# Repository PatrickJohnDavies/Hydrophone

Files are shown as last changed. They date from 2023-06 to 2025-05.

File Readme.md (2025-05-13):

# Intro
This project describes the construction of a stereo audio hydrophone system by building upon the hydrophone design from [Sound Sleuth](https://www.youtube.com/watch?v=KQ_KqJDaOM4). 
Major parts of the system are:
- Hydrophone with preampifier
- Amplifier and headphone driver
- Stand for underwater stereo sound seperation 

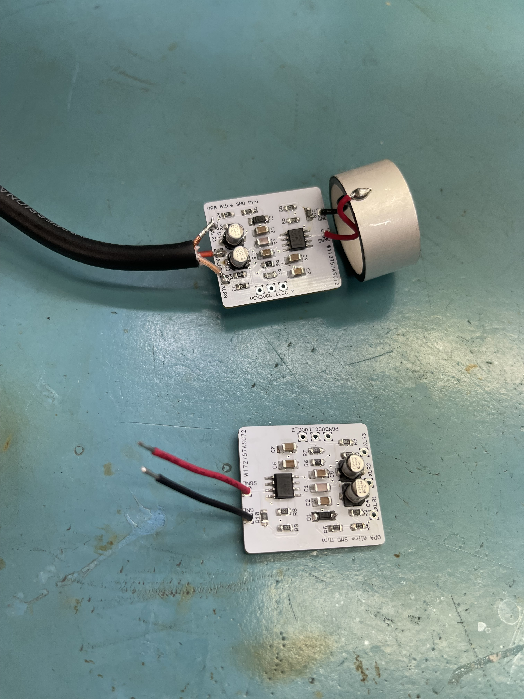
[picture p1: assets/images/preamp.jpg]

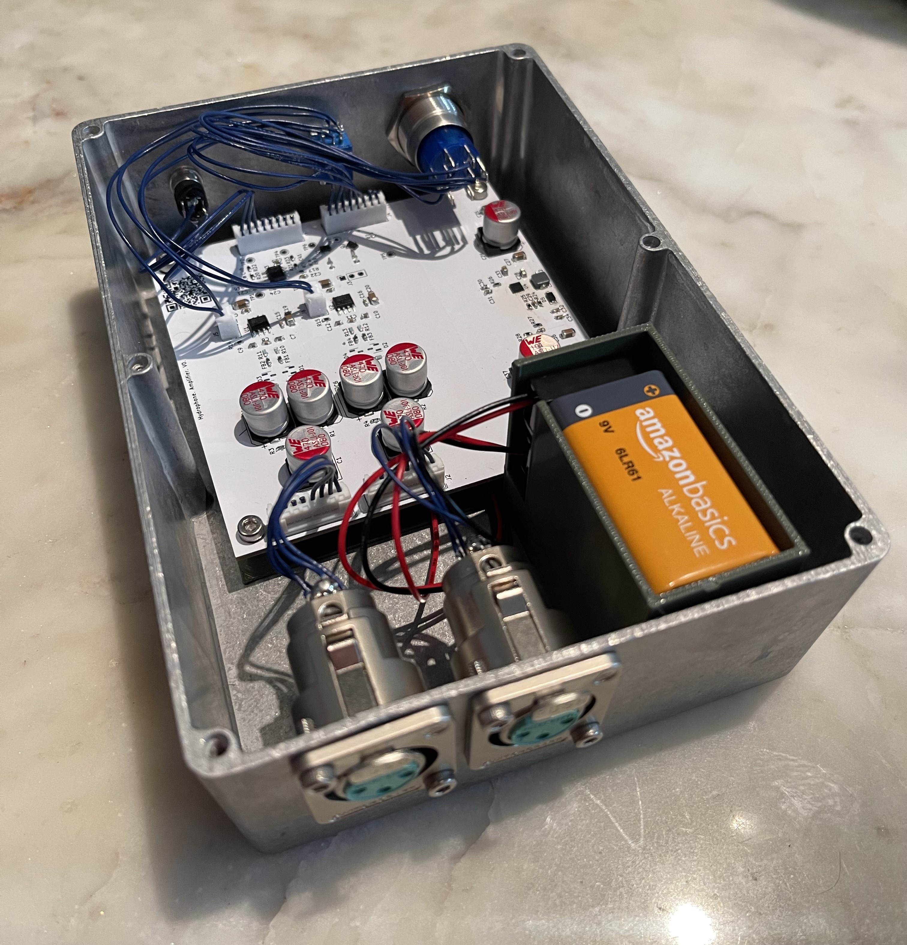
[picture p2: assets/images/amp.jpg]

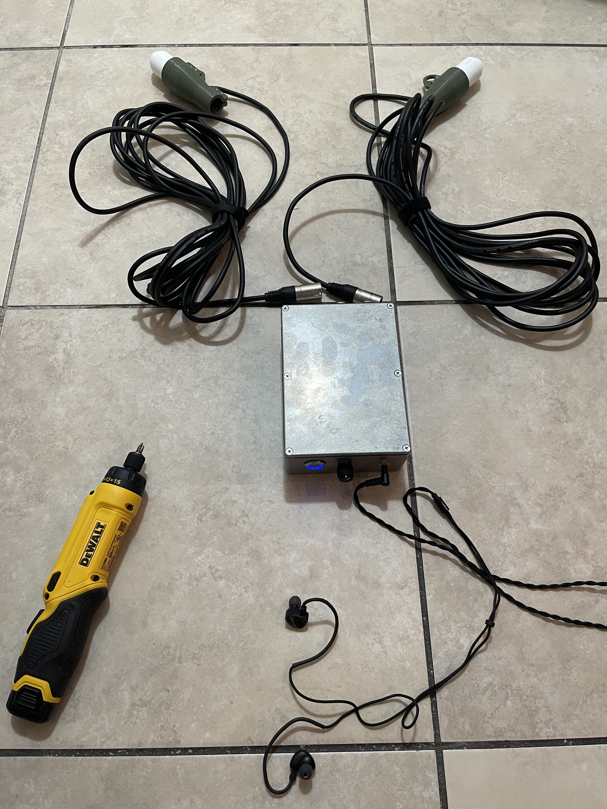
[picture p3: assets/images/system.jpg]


# Release Notes:
* V0
    * Bug. Instrumentation amplifier (U1, U2) footprint is incorrent. Therefore switched to AD620. Instrumentation amplifiers with this pinout seem have lower bandwidth.
    * Bug. Q2 has its drain and source reversed.

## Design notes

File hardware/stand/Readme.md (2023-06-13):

Human ear spacing: 0.175 m
Speed of sound in air: 331 m/s
Speed of sound in water: 1480 m/s
Hydrophone spacing in water: 0.175 m * 1480 m/s / 331 m/s = 0.782 m = 30.80 in

BOM:
- 4x https://www.homedepot.com/p/Charlotte-Pipe-1-2-in-PVC-Schedule-40-Socket-Cap-PVC021160600HD/203811669
- 4x https://www.homedepot.com/p/Charlotte-Pipe-1-2-in-PVC-Schedule-40-S-x-S-x-S-Tee-PVC024000600HD/203812195
- 2x https://www.homedepot.com/p/Charlotte-Pipe-1-2-in-x-10-ft-PVC-Schedule-40-Plain-End-DWV-Pipe-PVC-04005-0600/100348471
- 8x M3 Bolts

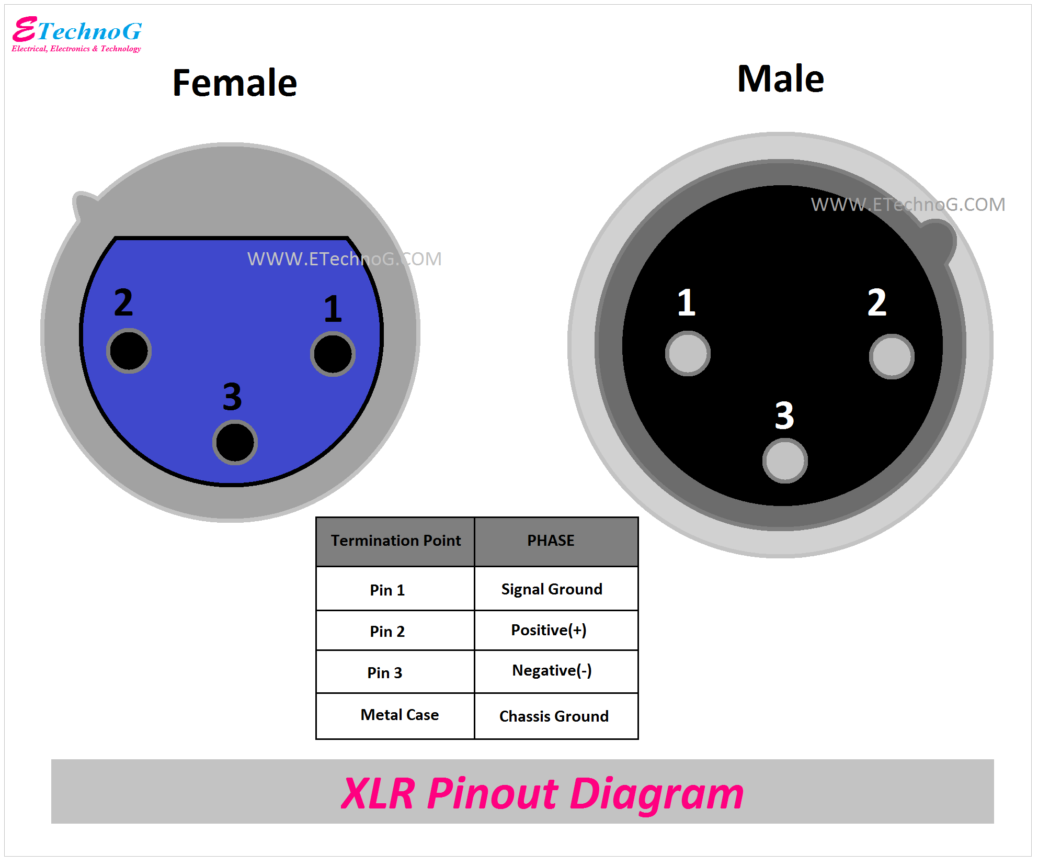
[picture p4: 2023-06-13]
hardware/pre amplifier/XLR Pinout Diagram.png

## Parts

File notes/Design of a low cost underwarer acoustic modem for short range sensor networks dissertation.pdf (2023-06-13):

UNIVERSITY OF CALIFORNIA, SAN DIEGO

Design of a Low-cost Underwater Acoustic Modem for Short-Range Sensor Networks

A thesis submitted in partial satisfaction of the requirements for the degree Doctor of Philosophy

in

Computer Science and Engineering

by

Bridget Benson

Committee in charge:

Professor Ryan Kastner, Chair Professor Rajesh Gupta
Professor John Hildebrand
Professor Tajana Rosing
Professor Curt Schurgers

2010

Copyright

Bridget Benson, 2010

All rights reserved.

The thesis of Bridget Benson is approved, and it is ac-

ceptable in quality and form for publication on microfilm

and electronically:

Chair

University of California, San Diego

2010

iii

DEDICATION

To everyone who told me not to give up.

iv

EPIGRAPH

Enjoy the Process

—Dr. Dan Clark

v

TABLE OF CONTENTS

Chapter 3 Comparison or RF, Optical and Acoustic Communication Un-

vi

vii

Chapter 8 System Tests | 111
8.1 Analog Testing | 111
8.2 Digital Testing | 114
8.2.1 | Hard Wired Tests | 114
8.2.2 | Bucket Tests | 118
8.3 Integrated Tests | 120
8.3.1 | Multipath Measurements | 120
8.3.2 | Tank Tests | 121
8.3.3 | Canyon View Pool Tests | 123
8.3.4 | Westlake Tests | 124
8.3.5 | Integrated System Test Summary | 128
8.4 Summary | 128
Chapter 9 Deployment Considerations | 130
9.1 Linear Programming Model | 130
9.2 Battery Considerations | 136
9.3 Housing Considerations | 137
9.4 Marine Life Considerations | 138
9.4.1 | Physical Effects | 138
9.4.2 | Acoustic Effects | 139
9.5 Summary | 140
Chapter 10 Future Improvements | 141
Appendix A Bill Of Materials | 143
Bibliography | 145

viii

LIST OF FIGURES

Figure 3.3: RF Wavelength vs. Frequency in Sea Water, Fresh Water, and

Figure 3.4: Air to Water Refraction Loss as a Function of Frequency . . . . 16

Figure 3.7: The Spectral Transmittance over the upper 10m of water for

Figure 3.8: Acoustic Absorption as a function of temperature, pressure, and

Figure 3.11: Source Level vs. Transmission Distance for a 40 kHz carrier an ambient noise of 50 dB re 1 uPa at various levels of SNR . . . . 28 Figure 3.12: Ray Trace for a 40kHz source with a 15 degree beam angle placed at 10 meters depth in a body of water 11 meters deep

Figure 5.1: (a) Raw PZT , (b) Prepotted Transducer , (c) and Potted Trans-

Figure 6.3: Class B Amplifier Input/Output Characteristic for one transistor 61 Figure 6.4: Class AB Amplifier Input/Output Characteristic for one tran-

Figure 6.5: Block diagram of a basic switching or PWM (Class-D) amplifier 63 Figure 6.6: Block diagram of the power amplifier design making use of a class AB and class D amplifier to achieve linearity and efficiency 63

ix

Figure 6.11: Maximum Power Transfer is acheived when ZS matches ZL . . 68
Figure 6.12: Electrical Equiavalent Circuit Model for a Transducer | 69
Figure 6.13: Measured and Simulated Current of the Transducer | 70
Figure 6.14: Measured and Simulated Impedance Magnitude of the Transducer 71 Figure 6.15: Measured and Simulated Impedance Phase of the Transducer . 72
Figure 6.16: Transducer Impedance Matching Circuit | 73
Figure 6.17: Impedance Matched Measured and Simulated Current of the
Transducer | 74
Figure 6.18: Impedance Matched Measured and Simulated Impedance Mag-
nitude of the Transducer | 75
Figure 6.19: Impedance Matched Measured and Simulated Impedance Phase
of the Transducer | 76
Figure 6.20: Estimated Power Coupled into the Transducer | 77
Figure 6.21: Receiver Block Diagram | 78
Figure 6.22: Overall Receiver Gain | 79

Figure 7.1: Block diagram of classic matched filter FSK demodulator . . . 82 Figure 7.2: Bit Error Rate of MFSK and MPSK for a given probability of
error | 83
Figure 7.3: Block diagram of a coherant PSK receiver | 84
Figure 7.4: Block Diagram of Complete Digital Receiver | 88
Figure 7.5: Block Diagram of FSK Modulator | 90
Figure 7.6: Block Diagram of Digital Down Converter | 91
Figure 7.7: Process of Symbol Synchronization | 92
Figure 7.8: Auto Correlation (blue) and Cross Correlation (black) of Orthogonal Gold (a), Walsh (b) and PN (c) Reference Codes . . . 95 Figure 7.9: MATLAB simulation of symbol synchronization for underwater
FSK | 97
Figure 7.10: Block Diagram of Symbol Synchronization for Underwater FSK 98 Figure 7.11: Hardware Units of Correlation Implementation for Underwater
FSK | 100
Figure 7.12: Control Structure of Symbol Synchronization for Underwater
FSK | 102
Figure 7.13: Block Diagram of Matched Filter FSK Demodulator | 104
Figure 7.14: (a) Clock Division, (b) Added Flip Flop between clock domain
to avoid metastability | 105
Figure 7.15: HW/SW Co-Design for the digital transceiver | 106
Figure 7.16: Digital Transceiver Control Flow. Interrupts are shown in red . 107

Figure 8.1: Mission Bay Test Set Up. (a) Transmitter on dock, (b) Receiver
on boat | 112
Figure 8.2: Mission Bay Receive Distances | 113
Figure 8.3: DINI DMEG-AD/DA Test Platform | 114

x

Figure 8.4: HyperTerminal Output Window showing correct transmission
of two hard wired packets | 115
Figure 8.5: ChipScope Internal Waveforms and signals from a 100-bit data
length test | 117
Figure 8.6: 12” Bucket Test | 118
Figure 8.7: Snapshot of hardware simulation result for 12” bucket test . . . 119 Figure 8.8: Multipath Amplitude Delay Profile at 0.5 m in the tank . . . . 122 Figure 8.9: Multipath Amplitude Delay Profile at 50m in the Canyon View
Pool | 123
Figure 8.10: Test Locations in Westlake | 125
Figure 8.11: Multipath Amplitude Delay Profile at 5m in Westlake | 126
Figure 8.12: Multipath Amplitude Delay Profile at 50m in Westlake | 126
Figure 8.13: Multipath Amplitude Delay Profile at 95m in Westlake | 127
Figure 8.14: System Test Results | 129
Figure 9.1: Santa Barbara RelocaTable Mooring (CHARM) | 133
Figure 9.2: Routing schemes for optimal cost and energy (for 6 month deployment) or lifetime (for 140kJ of energy) on the CHARM . . 135

xi

LIST OF TABLES

Table 2.1: 2009 Sensor Deployment around Moorea | | 5
Table 3.1: Rates, Ranges, and Uses of Wireless Fibre Systems RF Modems | 18
Table 3.2: Comparison or RF, optical and acoustic communication under-
water | 31
Table 4.1: Commercial Underwater Acoustic Modem Comparison | 36
Table 4.2: Research Underwater Acoustic Modem Comparison | 41
Table 6.1: Power Management Characteristics | 68
Table 7.1: Digital Transceiver Parameters | 89
Table 7.2: Digital Design Resource Usage | 108
Table 7.3: FPGA Power Consumption | 109
Table 7.4: Digital Transceiver Design Comparison | 109

Table 9.1: Data amounts for major sensors and sensor packages on the
CHARM | 134
Table 9.2: UCSDModem Power Characteristics | 134
Table 9.3: Minimum Energy and Cost Requirements for a 6 month deploy-
ment of the CHARM mooring | 136
Table A.1: Underwater Modem Bill of Materials | 144

xii

ACKNOWLEDGEMENTS

I would first and foremost like to thank my research team, Kenneth Domond,

Brian Faunce, and Ying Li, whose hard work on the modem transducer, analog

transceiver, and digital transceiver respecitvely is incorported in this text. I would

also like to thank all those who have provided advice and support to our modem

project including Don Kimball, Professor Curt Shurgers, Professor Feng Tong,

Doug Palmer, Cuong Vu, Diba Mirza, Feng Lu, Paul Roberts, Fernando Simonet,

Dr. Andrew Brooks, Professor Jules Jaffe, Professor Bill Hodgkiss, Jen Trezzo, S.N.

Hemanth Meenakshisundaram, Digvijay Dalapathi, Brent Hurley, Ethan Roth,

Daniel Johnson, and Barbara Lloyd.

I thank my advisor, Professor Ryan Kastner, for understanding my char-

acter and allowing me to explore many different exciting research areas before

focusing on a dissertation topic. I thank him for pushing me to become a teaching

assistant, apply for fellowships, and write research papers starting in my first year

of graduate school to force me to hit the ground running and keep the momen-

tum going throughout my graduate career. I also thank my committee members,

Professor Curt Schurgers, Professor Rajesh Gupta, Professor Tajana Rosing, and

Professor John Hildebrand, for guiding me through the writing of this thesis. I

would also like to thank Professor Sally MacIntyre, Professor Diana Franklin, Dr.

Grace Chang Spada, Professor Ron Iltis, and Professor Hua Lee for providing me

with assistance and direction throughout graduate school.

I am indebted to my many student colleagues for providing a positive and

fun environment in Santa Barbara and San Diego. I am especially grateful to Chris

Utley, Tricia Fu, Daniel Doonan, Arron Layns, Ali Irturk, Arash Arfaee, Shahnam

Mirzaei, Junguk Cho, Deborah Goshorn, Jason Oberg, Wei Hu, and Janarbek

Matay.

I would like to thank all my family and friends who have supported me on

my journey through graduate school and have made this dissertation possible. I

would especially like to thank my parents, Joann and Stan Benson, my sisters,

Gianna and Linda F´e Benson, and my significant other, Adam Volk, for always

beleiving in me and providing me with unconditional love and support.

xiii

Finally, I thank the National Science Foundation for providing me with a

Graduate Research Fellowship and my advisor with Grant #0816419 to support

the work described in this dissertation.

The text of Chapter 5, is currently being prepared for submission for pub-

lication of the material. The dissertation author was a co-primary researcher and

author (with Kenneth Domond). Ryan Kastner and Don Kimball directed and

supervised the research which forms the basis for Chapter 5.

The text of Chapter 7.3.3 is in part a reprint of the material as it appears in

the proceedings of the IEEE International Conference on Sensor Networks, Ubiq-

uitous, and Trustworthy Computing. The dissertation author was a co-primary

researcher and author (with Ying Li). The other co-authors listed on this publi-

cation [3] directed and supervised the research which forms the basis for Chapter

7.3.3.

The text of Chapter 7.3.1, 7.3.2, 7.3.4, and 7.3.6 is currently being prepared

for submission for publication of the material. The dissertation author is a co-

primary researcher and author (with Ying Li). Ryan Kastner and Xing Zhang

directed and supervised the research which forms the basis for Chapter 7.3.1, 7.3.2,

7.3.4, and 7.3.6.

Selections of Chapter 8 are in part a reprint of the material as it appears

in the proceedings of the IEEE Oceans Conference. The dissertation author was

a co-primary researcher and author along with Ying Li, Brian Faunce, and Ken-

neth Domond. The other co-authors listed on this publication [1] directed and

supervised the research which forms the basis for Chapter 8.

The ideas conveyed in the thesis are shared with the material in the pro-

ceedings of the IEEE Oceans Conference and the Embedded Systems Letters. The

dissertation author was a co-primary researcher and author along with Ying Li,

Brian Faunce, and Kenneth Domond. The other co-authors listed on these publi-

cations [1, 2] directed and supervised the research which forms the basis for the

dissertation.

xiv

VITA

2005 | B. S. in Computer Engineering summa cum laude, California Polytechnic State University, San Luis Obispo
2007 | M. S. in Electrical and Computer Engineering, University of California, Santa Barbara
2010 | Ph. D. in Computer Science and Engineering, University of California, San Diego

PUBLICATIONS

Bridget Benson, Ying Li, Brian Faunce, Kenneth Domond, Don Kimball, Curt Schurgers, and Ryan Kastner, “Design of a Low-Cost Underwater Acoustic Modem”, Embedded Systems Letters, accepted.

Bridget Benson, Ying Li, Brian Faunce, Kenneth Domond, Don Kimball, Curt Schurgers, and Ryan Kastner, “Design of a Low-Cost, Underwater Acoustic Modem for Short-Range Sensor Networks”, IEEE Oceans Conference, May 2010.

Ying Li, Bridget Benson, Ryan Kastner, and Xing Zhang, “Hardware Implementation of Symbol Synchronization for Underwater FSK”, IEEE International Conference on Sensor Networks, Ubiquitous, and Trustworthy Computing, June 2010.

Ying Li, Bridget Benson, Ryan Kastner, and Xing Zhang, “Bit Error Rate, Power, and Area Analysis of Multiple Implementations of Underwater FSK”, Engineering of Reconfigurable Systems and Algorithms, July 2009.

Bridget Benson, Ali Irturk, Junguk Cho and Ryan Kastner, “Energy Benefits of Reconfigurable Hardware for Use in Underwater Sensor Nets”, IEEE Reconfigurable Architectures Workshop, May 2009.

Bridget Benson, Ali Irturk, Junguk Cho, and Ryan Kastner, “Survey of Hardware Platforms for an Energy Efficient Implementation of Matching Pursuits Algorithm for Shallow Water Networks”, International Workshop on UnderWater Networks, September 2008.

Feng Tong, Bridget Benson, Ying Li, and Ryan Kastner, “Channel Equalization Based on Data Reuse LMS Algorithm for Shallow Water Acoustic Communication”, IEEE International Conference on Sensor Networks, Ubiquitous, and Trustworthy Computing, June 2010.

Bridget Benson, Frank Spada, Derek Manov, Grace Chang and Ryan Kastner, “Real Time Telemetry Options for Ocean Observing Systems”, European Telemetry Conference, April 2008.

xv

Bridget Benson, Grace Chang, Derek Manov, Brian Graham and Ryan Kastner, “Design of a Low-cost Acoustic Modem for Moored Oceanographic Applications”, International Workshop on Underwater Networks, September 2006.

Bridget Benson, Junguk Cho, Deborah Goshorn, and Ryan Kastner, “Field Programmable Gate Array Based Fish Detection Using Haar Classifiers”, American Academy of Underwater Sciences, March 2009.

Bridget Benson, Arash Arfaee, Choon Kim, Ryan Kastner, and Rajesh Gupta, “Integrating Embedded Computing Systems into High School and Early Undergraduate Education”, International Conference on Microelectronic Systems Education, July 2009.

Junguk Cho, Bridget Benson, Sunsern Cheamanukul, and Ryan Kastner, “Increased Performance of an FPGA-Based Color Classification System”, IEEE Symposium on Field-Programmable Custom Computing Machines, May 2010.

Junguk Cho, Bridget Benson, and Ryan Kastner, “Hardware Acceleration of Multiview Face Detection”, IEEE Symposium on Application Specific Processors, July 2009.

Junguk Cho, Bridget Benson, Shahnam Mirzaei, and Ryan Kastner. “Parallelized Architecture of Multiple Classifiers for Face Detection”, IEEE International Conference on Application-specific Systems, Architectures, and Processors, July 2009.

Ali Irturk, Bridget Benson, Shahnam Mirzaei and Ryan Kastner, “GUSTO: An Automatic Generation and Optimization Tool for Matrix Inversion Architectures”, ACM Transactions on Embedded Computing Systems.

Ali Irturk, Bridget Benson, Nikolay Laptev and Ryan Kastner, “Architectural Optimization of Decomposition Algorithms for Wireless Communication Systems”, IEEE Wireless Communications and Networking Conference (WCNC 2009), April 2009.

Ali Irturk, Bridget Benson and Ryan Kastner, “Automatic Generation of Decomposition based Matrix Inversion Architectures”, IEEE International Conference on Field-Programmable Technology (ICFPT), December 2008.

Ali Irturk, Bridget Benson, Nikolay Laptev and Ryan Kastner, “FPGA Acceleration of Mean Variance Framework for Optimum Asset Allocation”, Workshop on High Performance Computational Finance at SC08 International Conference for High Performance Computing, Networking, Storage and Analysis, November 2008.

Ali Irturk, Bridget Benson, Shahnam Mirzaei and Ryan Kastner, “An FPGA Design Space Exploration Tool for Matrix Inversion Architectures”, IEEE Symposium on Application Specific Processors (SASP), June 2008.

xvi

ABSTRACT OF THE DISSERTATION

Design of a Low-cost Underwater Acoustic Modem for Short-Range Sensor Networks

by

Bridget Benson

Doctor of Philosophy in Computer Science and Engineering

University of California, San Diego, 2010

Professor Ryan Kastner, Chair

Small, dense, wireless sensor networks are beginning to revolutionize our

understanding of the physical world by providing fine resolution sampling of the

surrounding environment. The ability to have many small devices streaming real-

time data physically distributed near the objects being sensed brings new oppor-

tunities to observe and act on the world which could provide significant benefits

to mankind.

While wireless sensor-net systems are beginning to be fielded in applications

today on the ground, underwater sensor nets remain quite limited by comparison.

Still, a large portion of ocean research is conducted by placing sensors (that mea-

sure current speeds, temperature, salinity, pressure, bioluminescence, chemicals,

etc.) into the ocean and later physically retrieving them to download and analyze

their collected data. Real-time underwater wireless sensor networks that do exist

are often sparsely deployed over wide areas.

The existence of small, dense wireless sensor networks on land was made

possible by the advent of low-cost radio platforms. These radio platforms cost a

xvii few hundred U.S. dollars enabling researchers to purchase many nodes with a fixed

budget allowing for dense, short-range deployment. The aquatic counterpart to the

terrestrial radio is the underwater acoustic modem. Existing underwater acoustic

modems’ power consumption, ranges, and price points are all designed for sparse,

long-range, expensive systems rather than for small, dense, and inexpensive sensor-

nets. It is widely recognized that an aquatic counterpart to inexpensive terrestrial

radio would be required to enable deployment of small dense underwater wireless

sensor networks for advanced underwater ecological analyses.

This thesis describes the full design of an underwater acoustic modem for

small, dense wireless sensor networks starting with the most critical component

from a cost perspective - the transducer. The design replaces a commercial un-

derwater transducer with a homemade underwater transducer using inexpensive

piezoceramic material and builds the rest of the modem’s components around the

properties of the homemade transducer to extract as much performance as possible.

By building the modem from inexpensive components, the design provides a low-

cost, low-power alternative to existing commercial modems for use in short-range

networks.

xviii

# Chapter 1

# Introduction

Small, dense, wireless sensor networks are beginning to revolutionize our

understanding of the physical world by providing fine resolution sampling of the

surrounding environment. The ability to have many small devices streaming real-

time data physically distributed near the objects being sensed brings new oppor-

tunities to observe and act on the world which could provide significant benefits to

mankind. For example, dense wireless sensor networks have been used in agricul-

ture to improve the quality, yield and value of crops, by tracking soil temperatures

and informing farmers of fruit maturity and potential damages from freezing tem-

peratures [4]. They have been deployed in sensitive habitats to monitor the causes

for mortality in endangered species [5]. Dense wireless sensor networks have also

been used to detect structural damages on bridges and other civil structures to

inform authorities of needed repair [6] and have been used to monitor the vibra-

tion signatures of industrial equipment in fabrication plants to predict mechanical

failures [7].

While wireless sensor-net systems are beginning to be fielded in applications

on the ground, underwater sensor nets remain quite limited by comparison [8]. Still,

a large portion of ocean research is conducted by placing sensors (that measure

current speeds, temperature, salinity, pressure, bioluminescence, chemicals, etc.)

into the ocean and later physically retrieving them to download and analyze their

collected data. This method does not provide for real-time analysis of data which

is critical for event prediction. Real-time underwater wireless sensor networks that do exist are often sparsely deployed over wide areas. For example, the Deep-ocean

Assessment and Reporting of Tsunami (DART) project consists of 39 stations

worldwide acquiring critical data for early detection of tsunamis [12]. The FRONT

network consists of about 10 subsurface wirelessly networked sensors spaced about

9km apart in the inner continental shelf outside Block Island Sound to increase

scientific understanding of the coastal ocean [9]. The SeaWeb network consists of

tens of nodes spaced 2-5km apart for oceanographic telemetry, underwater vehicle

control, and other uses of underwater wireless digital communications [10, 11].

Other real-time networks that exist are wired and extremely expensive [13, 14, 15,

16].

The existence of small, dense wireless sensor networks on land was made

possible by the advent of low-cost radio platforms such as PicoRadio and Mica2

[17, 18]. These radio platforms cost a few hundred U.S. dollars enabling researchers

to purchase many nodes with a fixed budget allowing for dense, short-range deploy-

ment. The aquatic counterpart to the terrestrial radio is the underwater acoustic

modem. There are a number of acoustic modems currently available including com-

mercial offerings from companies like Teledyne Benthos, DSPComm, LinkQuest

and Tritech and academic projects, most notably the WHOI MicroModem. Unfor-

tunately, these existing modems’ power consumption, ranges, and price points are

all designed for sparse, long-range, expensive systems rather than small, dense, and

inexpensive sensor-nets [8, 19, 20]. It is widely recognized that an aquatic counter-

part to inexpensive terrestrial radio is required to enable deployment of small dense

underwater wireless sensor networks for advanced underwater ecological analyses.

Thesis Statement: This thesis describes the design of a short-range un-

derwater acoustic modem starting with the most critical component from a cost

perspective - the transducer. The transducer is the device that converts electri-

cal energy to/from acoustic energy, which is equivalent to the antenna in radios.

The design substitutes a commercial underwater transducer with a home-made

underwater transducer using cheap piezoceramic material and builds the rest of

the modem’s components around the properties of the transducer to extract as

much performance as possible. The modem provides bit rates of up to 200 bps for ranges up to 400 m at a components cost of ∼ $350 U.S. The major contributions

of this thesis are:

- The design and analysis of a low-cost omni-directional transducer
- The design of a novel acoustic analog transceiver
- The design of a field programmable gate array (FPGA) implementation of a

frequency shift keying (FSK) based digital transceiver that provides compa-

rable power consumption to other underwater digital transceiver designs

- A field-tested, proof-of-concept system prototype of a low-cost underwater

acoustic modem that consists of the low-cost omni-directional transducer,

the novel analog transceiver, and FPGA FSK based digital transceiver

- A linear programming model that optimizes for cost, energy consumption or

deployment time for underwater modems deployed on a linear underwater

network

This thesis is organized as follows: Chapter 2 describes a few applications

of small, dense networks, that would be enabled if a low-cost underwater acoustic

modem were available. Chapter 3 describes the selection of using acoustic modems

(instead of RF or optical modems) for underwater communication based on the

physics of the underwater environment. Chapter 4 describes existing commercial

and research underwater acoustic modems to illustrate the novelty and applicabil-

ity of our design. Chapters 5, 6, and 7 describe the transducer, analog transceiver,

and digital transceiver design of the modem (hereinafter referred to as the UCSD-

Modem) respectively. Chapter 8 reports analog, digital, and system test results of

the UCSDModem from simulations, a test tank, and the field. Chapter 9 describes

deployment considerations for the UCSDModem including a linear programming

model to determine cost, energy, and lifetime of a deployment, as well as battery,

housing, and marine life considerations. We conclude the thesis in Chapter 10 with

a disucssion on possible future improvemetns to the modem design. The complete

bill of materials (BOM) is included in the Appendix.

# Chapter 2

# Motivating Applications

This chapter describes a few dense underwater sensor network applications

that motivate the need for a low-cost underwater acoustic modem, including appli-

cations involving coral reefs, autonomous drifter swarms, shallow-water moorings,

and power plants. We describe the application and its socio-scientific impact and

describe how a low-cost underwater acoustic modem can enable or improve the

application for further scientific advancement. We conclude by summarizing the

common requirements of these applications.

## 2.1 Coral Reefs

Coral reefs are of prime ecological and economic importance, having the

highest species diversity of any marine habitat. Unfortunately, they are under

stress due to increasing temperature and acidity of the oceans, episodic pulses

from major storms, and heightened incidence of disease.

Because of the complexity of coral reef ecosystems, there is an incomplete

understanding of the processes that collectively determine their structure, func-

tion and dynamics. Fundamental to efforts to understand coral reef ecosystems

is a broad suite of environmental observations ranging from basic environmen-

tal factors such as water temperature, salinity and bio-optical variables, to more

complex measurements such as nutrient concentration, the presence/absence of

environmental estrogens, volatile hydrocarbons, and pathogenic bacteria. More complex observations include tracking fishes and monitoring currents including

flows of nutrients in the reef. The opportunities for enhancing marine science

through the development of advanced sensing systems are seemingly endless.

The University of California’s Gump Research Station on the island of

Moorea, French Polynesia, is the National Science Foundation’s coral reef long

term ecological research (LTER) site. Moorea is a high, 1.2 million year old vol-

canic island surrounded by a well-developed coral reef and lagoon system. The

coastal environments of Moorea offer an excellent opportunity for studies of coral

reef ecosystems. An offshore barrier reef forms a system of shallow, narrow la-

goons around the 60 km perimeter of Moorea [21]. All major coral reef types are

present and accessible by small boat. The reefs are in excellent condition and have

been subject to relatively few natural disturbances in the last several decades. The

cover of coral and abundance of reef fishes are high, and the Territorial Government

recently set aside large tracts of reefs around Moorea as protected areas.

Table 2.1: 2009 Sensor Deployment around Moorea
Instrument | Quantity | Unit Cost | Sampling Regime
RDI Workhorse Sentinel Acoustic Doppler Current Profiler | 3 | $35000 | 15 pings every minute at 120 Hz for currents 20 pings every 3 hours at 120KHz for waves
Seabird SBE26+ Wave/Tide Recorders | 3 | $19000 | Every 20 minutes for 60 seconds for tides and 4096 samples at 240Hz for waves
Seabird SBE39 Thermistor and Pressure sensor | 8 | $1500 | Every 2 minutes
Seabird SBE37 CTD recorder | 8 | $6000 | Every 2 minutes
Onset temperature loggers | 12 | $110 | Every 2 minutes
Seabird SBE39 thermistors | 35 | $1000 | Every 2 minutes

The present state of sensing systems in Moorea is primitive; ecological re-

search could be significantly enhanced with appropriate technology. Currently, scuba divers deploy sensors with data loggers. The sensors are typically deployed

for months at a time, then recovered for cleaning, battery replacement, and data

offload. Figure 2.1 shows the 2009 sensor deployment around the island and Table

2.1 describes the types, quantity, cost, and sampling regimes of these sensors.

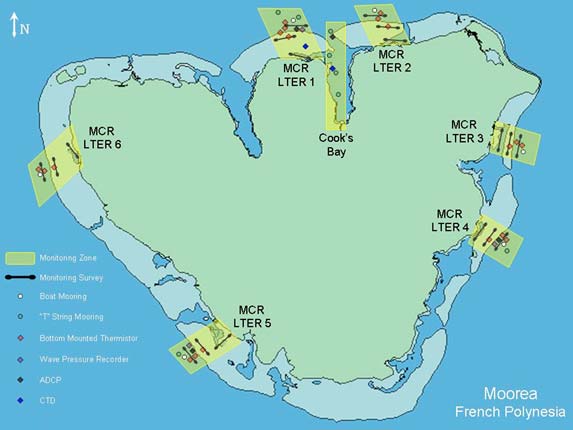
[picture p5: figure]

Figure 2.1: 2009 Sensor Deployment around Moorea

The ability to perform real-time, adaptive ecological experiments would

represent a significant advance in ecological sensing. The grand vision is a ‘Digi-

tal Moorea’: a prototype observation system which produces an accurate, virtual

digital representation of Moorea’s coral reefs updated by real-time adaptive sam-

pling. As underwater cabling requires extensive environmental permitting and can

be damaging to the reefs, a wireless networking option is necessary to make Digital

Moorea a reality. As sensors in a monitoring area are currently less than 500m

apart (Figure 2.1) , and the majority of the sensors deployed (i.e. thermistors)

have low data rates (Table 2.1), expensive, long-range, high data rate commercial

underwater modems are excessive and cost-prohibitive for this application. Thus a low-cost underwater acoustic modem intended for dense, short-range, low data-rate

applications would be well suited to enable advanced monitoring in coral reefs.
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

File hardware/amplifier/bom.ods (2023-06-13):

# | Reference | Qty | Value
1 | BT1, BT2 | 2 | 9V | B2B-PH-K-S(LF)(SN) | $0.17 | $0.34 | https://www.digikey.com/en/products/detail/jst-sales-america-inc/B2B-PH-K-S-LF-SN/926611
2 | C1, C2, C3, C4, C5, C6, C26 | 7 | 47u | 865081757008 | $0.90 | $6.30 | https://www.digikey.com/en/products/detail/w%C3%BCrth-elektronik/865081757008/17829961
3 | C7, C9, C10, C12, C30 | 5 | 1n | CL10C102JB8NNNC | $0.10 | $0.50 | https://www.digikey.com/en/products/detail/samsung-electro-mechanics/CL10C102JB8NNNC/3886749
4 | C8, C11, C39 | 3 | 10n | CL10B103KB8NNNC | $0.10 | $0.30 | https://www.digikey.com/en/products/detail/samsung-electro-mechanics/CL10B103KB8NNNC/3886667
5 | C13, C14, C15, C16, C23, C24 | 8 | 0.1u | CL10B104KB8NNNC | $0.10 | $0.80 | https://www.digikey.com/en/products/detail/samsung-electro-mechanics/CL10B104KB8NNNC/3886658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
6 | C17, C18, C19, C20, C27, C36 | 6 | 10u | CL31A106KBHNNNE | $0.33 | $1.98 | https://www.digikey.com/en/products/detail/samsung-electro-mechanics/CL31A106KBHNNNE/3890962
7 | C21, C22, C40, C41 | 2 | DNP
8 | C25 | 1 | 4.7u | 12065C475KAT2A | $0.41 | $0.41 | https://www.digikey.com/en/products/detail/kyocera-avx/12065C475KAT2A/2676431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
9 | C28, C33, C38 | 3 | 1u | CL21B105KBFNNNG | $0.11 | $0.33 | https://www.digikey.com/en/products/detail/samsung-electro-mechanics/CL21B105KBFNNNG/3894467
10 | C29 | 1 | 0.22u | CL10B224KA8NNNC | $0.10 | $0.10 | https://www.digikey.com/en/products/detail/samsung-electro-mechanics/CL10B224KA8NNNC/3886769
11 | C31 | 1 | 10p | CL10C100CB8NNNC | $0.10 | $0.10 | https://www.digikey.com/en/products/detail/samsung-electro-mechanics/CL10C100CB8NNNC/3886727
12 | C32, C34 | 2 | 0.1u | CL10B104KC8NNNC | $0.10 | $0.20 | https://www.digikey.com/en/products/detail/samsung-electro-mechanics/CL10B104KC8NNNC/5961291
13 | C35 | 1 | 4.7p | CL10C4R7BB8NNNC | $0.10 | $0.10 | https://www.digikey.com/en/products/detail/samsung-electro-mechanics/CL10C4R7BB8NNNC/3887450
14 | C37 | 1 | 100u | 865080757014 | $0.94 | $0.94 | https://www.digikey.com/en/products/detail/w%C3%BCrth-elektronik/865080757014/17829842
15 | D1, D2, D3, D4 | 4 | BAV199 | BAV199,215 | $0.22 | $0.88 | https://www.digikey.com/en/products/detail/nexperia-usa-inc/BAV199-215/763223
16 | D5 | 1 | DFLS260-7 | DFLS260-7 | $0.48 | $0.48 | https://www.digikey.com/en/products/detail/diodes-incorporated/DFLS260-7/4249911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
17 | D6 | 1 | 1N4148 | 1N4148W-TP | $0.12 | $0.12 | https://www.digikey.com/en/products/detail/micro-commercial-co/1N4148W-TP/717196
18 | FB1, FB2, FB3, FB4 | 4 | FerriteBead | 742792651 | $0.18 | $0.72 | https://www.digikey.com/en/products/detail/w%C3%BCrth-elektronik/742792651/1638997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
19 | J1, J2, J4, J7 | 4 | Conn_01x04 | B8B-PH-K-S(LF)(SN) | $0.44 | $1.76 | https://www.digikey.com/en/products/detail/jst-sales-america-inc/B8B-PH-K-S-LF-SN/926617
20 | J3 | 1 | Conn_01x03
21 | J5, J6 | 2 | Conn_01x02 | B2B-PH-K-S(LF)(SN) | $0.17 | $0.34 | https://www.digikey.com/en/products/detail/jst-sales-america-inc/B2B-PH-K-S-LF-SN/926611
22 | L1 | 1 | 0.47u | 74479876147C | $0.70 | $0.70 | https://www.digikey.com/en/products/detail/w%C3%BCrth-elektronik/74479876147C/5870836
23 | L2 | 1 | 6.8u | 74437324068 | $2.35 | $2.35 | https://www.digikey.com/en/products/detail/w%C3%BCrth-elektronik/74437324068/2791049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
24 | Q1, Q2 | 2 |  | SSM3J338R,LF | $0.37 | $0.74 | https://www.digikey.com/en/products/detail/toshiba-semiconductor-and-storage/SSM3J338R-LF/5810226
25 | Q3 | 1 | SBCP56-16T1G | SBCP56-16T1G | $0.41 | $0.41 | https://www.digikey.com/en/products/detail/onsemi/SBCP56-16T1G/3062655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
26 | R1, R2, R3, R4 | 4 | 6.8k | ERA-3AED682V | $0.27 | $1.08 | https://www.digikey.com/en/products/detail/panasonic-electronic-components/ERA-3AED682V/9373539
27 | R5, R6, R7, R8, R9 | 5 | 2.2k | MCT06030C2201FP500 | $0.15 | $0.75 | https://www.digikey.com/en/products/detail/vishay-beyschlag-draloric-bc-components/MCT06030C2201FP500/2607839
28 | R10, R11, R12, R13 | 4 | 33 | MCT06030C3309FP500 | $0.17 | $0.68 | https://www.digikey.com/en/products/detail/vishay-beyschlag-draloric-bc-components/MCT06030C3309FP500/2607849
29 | R14, R15, R20, R21, R22, R23 | 6 | 0 | CRCW06030000Z0EC | $0.10 | $0.60 | https://www.digikey.com/en/products/detail/vishay-dale/CRCW06030000Z0EC/5070621
30 | R16, R17, R18, R19 | 4 | DNP
31 | R24 | 1 | 100k | CRCW0603100KFKEA | $0.10 | $0.10 | https://www.digikey.com/en/products/detail/vishay-dale/CRCW0603100KFKEA/1174896
32 | R25, R26 | 1 | 22k | CRCW060322K0FKEA | $0.10 | $0.10 | https://www.digikey.com/en/products/detail/vishay-dale/CRCW060322K0FKEA/1174818
33 | R27 | 1 | 1M | CRCW06031M00FKEA | $0.10 | $0.10 | https://www.digikey.com/en/products/detail/vishay-dale/CRCW06031M00FKEA/1175010
34 | R28 | 1 | 34.8k | CRCW060334K8FKEA | $0.10 | $0.10 | https://www.digikey.com/en/products/detail/vishay-dale/CRCW060334K8FKEA/1174842
35 | R29 | 1 | 499 | CRCW0603499RFKEAC | $0.10 | $0.10 | https://www.digikey.com/en/products/detail/vishay-dale/CRCW0603499RFKEAC/7928408
36 | TP1, TP2, TP3, TP4, TP5, TP6, TP7, TP8 | 8 | TestPoint
37 | U1, U2 | 2 | AD8421 | AD8421ARZ-R7 | $9.16 | $18.32 | https://www.digikey.com/en/products/detail/analog-devices-inc/AD8421ARZ-R7/3542848
 |  | 2 | AD620 | AD620ARZ-REEL7 | $12.53 | $25.06 | https://www.digikey.com/en/products/detail/analog-devices-inc/AD620ARZ-REEL7/617757
38 | U3 | 1 | OPA1688 | OPA1688IDR | $1.77 | $1.77 | https://www.digikey.com/en/products/detail/texas-instruments/OPA1688IDR/5481842
39 | U4 | 1 | LT8362 | LT8362EDD#PBF | $6.12 | $6.12 | https://www.digikey.com/en/products/detail/analog-devices-inc/LT8362EDD-PBF/7599737
 | Enclosure | 1 |  | 1550WE | $18.46 | $18.46 | https://www.digikey.com/en/products/detail/hammond-manufacturing/1550WE/2211564
 | Rubber feet | 4 |  | SJ5402 | $0.20 | $0.80 | https://www.digikey.com/en/products/detail/3m/SJ5402/3866081
 | Power switch | 1 |  | ULV4F2GSS341 | $18.07 | $18.07 | https://www.digikey.com/en/products/detail/e-switch/ULV4F2GSS341/5299300
 | 9V battery connector with cable | 2 |  | 84-8 | $0.68 | $1.36 | https://www.digikey.com/en/products/detail/keystone-electronics/84-8/304015
 | XLR connector | 2 |  | DE3F | $8.46 | $16.92 | https://www.digikey.com/en/products/detail/switchcraft-inc/DE3F/4863750
 | XLR jst cable | 2 |  | A08KR08KR26E254A | $1.75 | $3.50 | https://www.digikey.com/en/products/detail/jst-sales-america-inc/A08KR08KR26E254A/9920962
 | 1/8 “ stereo connector | 1 |  | SJ1-43502PM | $2.30 | $2.30 | https://www.digikey.com/en/products/detail/cui-devices/SJ1-43502PM/5130707
 | 1/8 “ stereo connector cable | 1 |  | A02KR02KR26E254B | $1.19 | $1.19 | https://www.digikey.com/en/products/detail/jst-sales-america-inc/A02KR02KR26E254B/9920927
 | Volume pot | 1 |  | PTD902-2015K-A103 | $2.91 | $2.91 | https://www.digikey.com/en/products/detail/bourns-inc/PTD902-2015K-A103/3820463
 | Volume pot knob | 1 |  | OEDL-63-2-7 | $10.66 | $10.66 | https://www.digikey.com/en/products/detail/kilo-international/OEDL-63-2-7/710708
 | Volume pot jst cable | 1 |  | A02KR02KR26E254B | $1.19 | $1.19 | https://www.digikey.com/en/products/detail/jst-sales-america-inc/A02KR02KR26E254B/9920927
 |  |  |  |  |  | $153.14
 | R | Cc | Fc=cm [kHz] | Cd | Fc-diff [kHz]
 | 33 | 1.00E-09 | 4822.87706339077 | 1.00E-08 | 229.660812542418

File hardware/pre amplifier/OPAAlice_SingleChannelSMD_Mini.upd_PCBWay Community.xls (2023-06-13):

SHOPPING CART
This is not an invoice
19-Oct-21 09:47:17
 | Mouser # | Mfr. # | Manufacturer | Customer # | Description | RoHS | Lifecycle | Order Qty. | Price (USD) | Ext.: (USD)
1 | 187-CL31A226KAHNNWE | CL31A226KAHNNWE | Samsung Electro-Mechanics | C2,5,7 | Multilayer Ceramic Capacitors MLCC - SMD/SMT 22uF+/-10% 25V X5R 3216 | RoHS Compliant | New At Mouser | 30 | $0.411 | $12.33
2 | 810-CGA5L2C0G1H104J | CGA5L2C0G1H104J160AA | TDK | C1,6 | Multilayer Ceramic Capacitors MLCC - SMD/SMT CGA 1206 50V 0.1uF C0G 5% AEC-Q200 | RoHS Compliant |  | 20 | $0.361 | $7.22
3 | 647-UCM1E220MCL1GS | UCM1E220MCL1GS | Nichicon | C3,4 | Aluminum Electrolytic Capacitors - SMD 25V 22uF TOL 20% AEC-Q200 | RoHS Compliant |  | 20 | $0.392 | $7.84
4 | 667-ERA-6AED222V | ERA-6AED222V | Panasonic | R3,4,8,9 | Thin Film Resistors - SMD 0805 2200ohms 25ppm 0.5% AEC-Q200 | RoHS Compliant By Exemption |  | 40 | $0.108 | $4.32
5 | 667-ERA-6AED470V | ERA-6AED470V | Panasonic | R1,2 | Thin Film Resistors - SMD 0805 47ohms 25ppm 0.5% AEC-Q200 | RoHS Compliant By Exemption |  | 20 | $0.09 | $1.80
6 | 603-RT0805DRD0747KL | RT0805DRD0747KL | YAGEO | R6,7 | Thin Film Resistors - SMD 47K OHM .5% 25PPM 1/8W | RoHS Compliant By Exemption |  | 20 | $0.19 | $3.80
7 | 603-RT0805DRD071ML | RT0805DRD071ML | YAGEO | R10 | Thin Film Resistors - SMD 1M OHM .5% 25PPM 1/8W | RoHS Compliant By Exemption |  | 10 | $0.146 | $1.46
8 | 595-OPA1642AIDR | OPA1642AIDR | Texas Instruments | IC1 | Audio Amplifiers Sound-Plus Hi-Perf JFET-Inp Aud Op Amp | RoHS Compliant |  | 10 | $2.24 | $22.40
9 | 667-ERA-6AED201V | ERA-6AED201V | Panasonic | R5 | Thin Film Resistors - SMD 0805 200ohms 25ppm 0.5% AEC-Q200 | RoHS Compliant By Exemption |  | 10 | $0.051 | $0.51
10 | 78-MMSZ5242C-HE3-08 | MMSZ5242C-HE3-08 | Vishay | D1 | Zener Diodes 12 Volt 0.5W 2% AUTO | RoHS Compliant |  | 10 | $0.206 | $2.06
By submitting your order you agree to these terms and conditions. (https://www.mouser.com/saleterms) |  |  |  |  |  |  |  |  | Merchandise: | $63.74
Prices are reflected at the date and time shown. |  |  |  |  |  |  |  |  | Shipping Charge: | $0.00

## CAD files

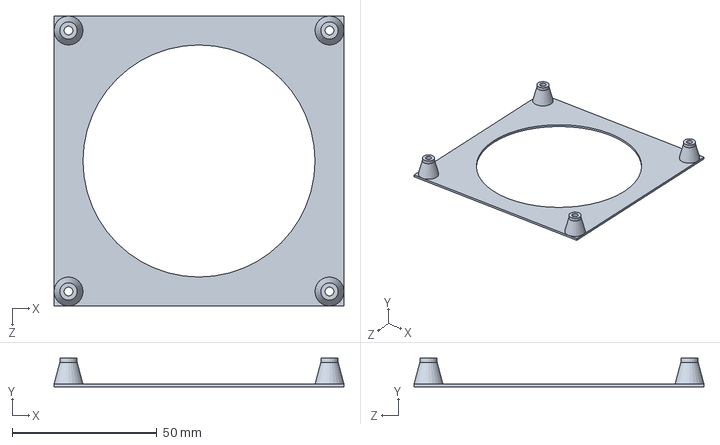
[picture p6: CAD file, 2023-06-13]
hardware/enclosure/stand.SLDPRT
100.0 x 10.0 x 100.0 mm

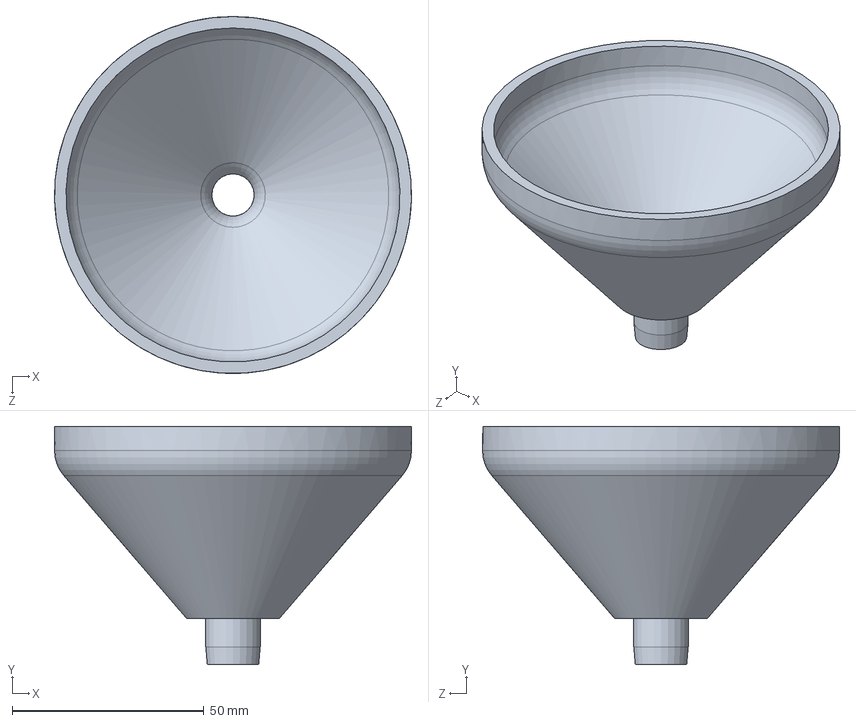
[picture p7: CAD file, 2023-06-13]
hardware/stand/funnel.SLDPRT
93.0 x 62.0 x 93.0 mm

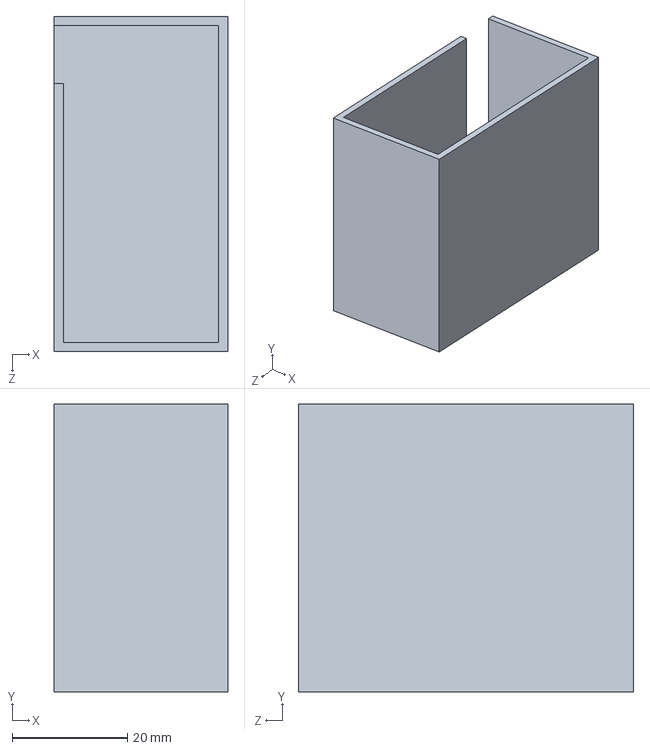
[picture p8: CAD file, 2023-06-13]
hardware/enclosure/9v battery compartment.SLDPRT
30.2 x 50.0 x 58.2 mm

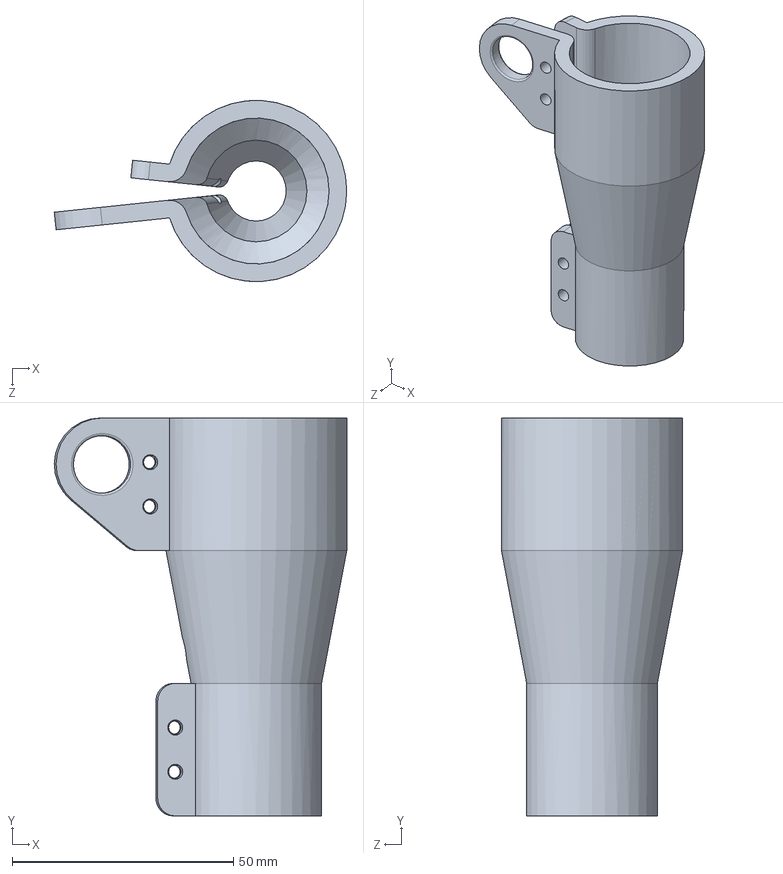
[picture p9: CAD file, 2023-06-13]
hardware/stand/hydrophone to pvc coupler.SLDPRT
66.2 x 90.0 x 40.9 mm

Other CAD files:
hardware/enclosure/9v battery compartment.STL
hardware/enclosure/stand.STL
hardware/stand/funnel.STL
hardware/stand/hydrophone to pvc coupler.STL

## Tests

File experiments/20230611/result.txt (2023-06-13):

Goals:
    Qualitateviely evaluate the design
    Hear propeller noise
    Hopefully hear a Dolphin squeek

Site:
    Located the hydrohphones 25 ft of the Bear Cut bridge in Miami. Site was chosen because it was near a popular boat channel.

Setup:
    The left and right hyrdrophone were suspended in the water column by the "stand". Approxitmately 30" apart.
    They plugged into the amplifier and the resulting sound was listened to through headphones.

Result:
    Even though the waves were relatively calm there was a predominant high frequency rustling noise. 
    With the gain cranked to about 3/4 it was possible to hear propeller noise at 400 to 500 meters from accelerating recreational motor boats. 
    Ambient noise at this level was almost overwhelming though. Spectral analysis would have been nice to see if analog filtering would be effective.
    Idling motor boats were not immeditaley detectable.
    Sound bearing determination with the stereo hydrophones was not immeditaley apparent.
    Recording with an iphone dongle was not working unfortunately.

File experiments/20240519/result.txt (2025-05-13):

Goals:
    Record hydrophone audio through phone

Site:
    Beach. Hydrophone dropped into water 6 feet from shore.

Result:
    Good enviromental sounds pickup.

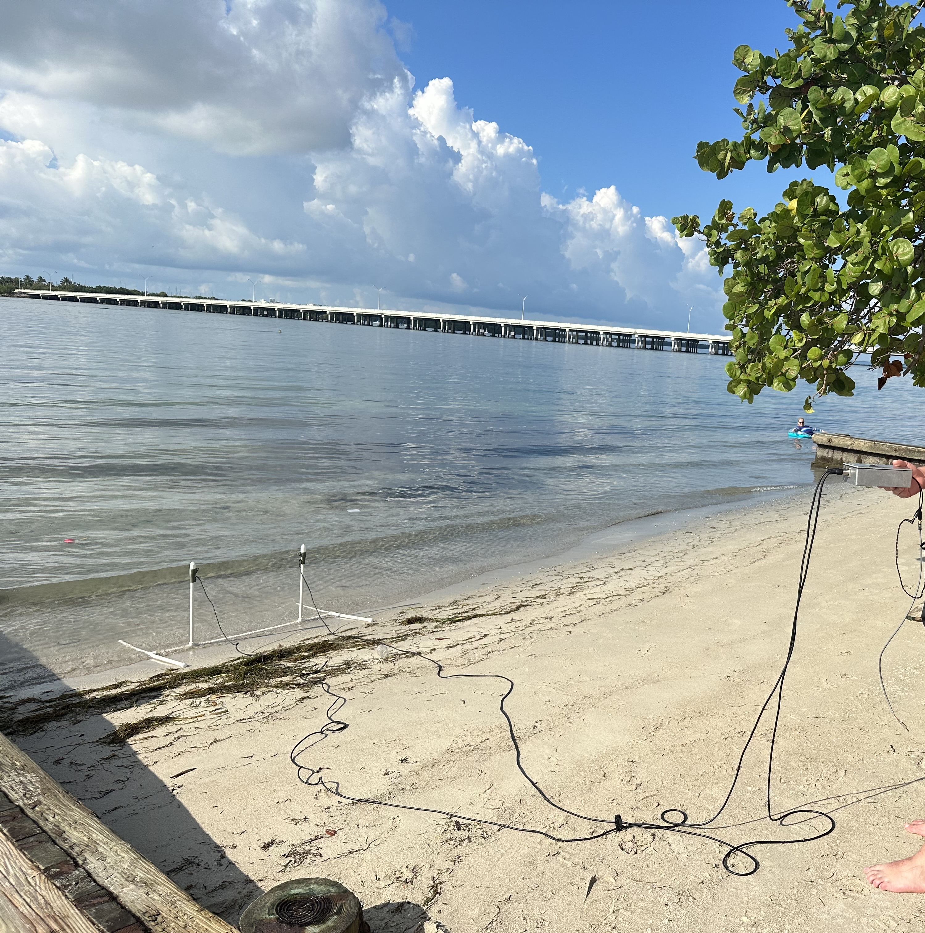
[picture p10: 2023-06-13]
experiments/20230611/beached hydrophones.jpg

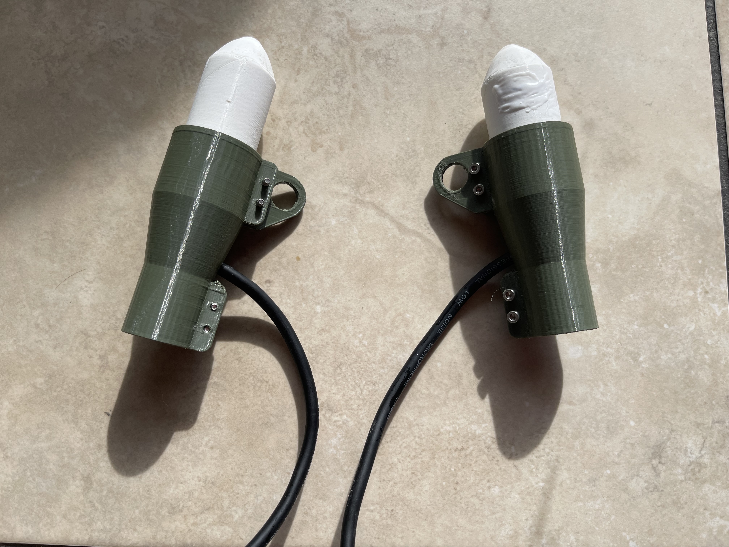
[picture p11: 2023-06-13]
experiments/20230611/hydrophones.jpg

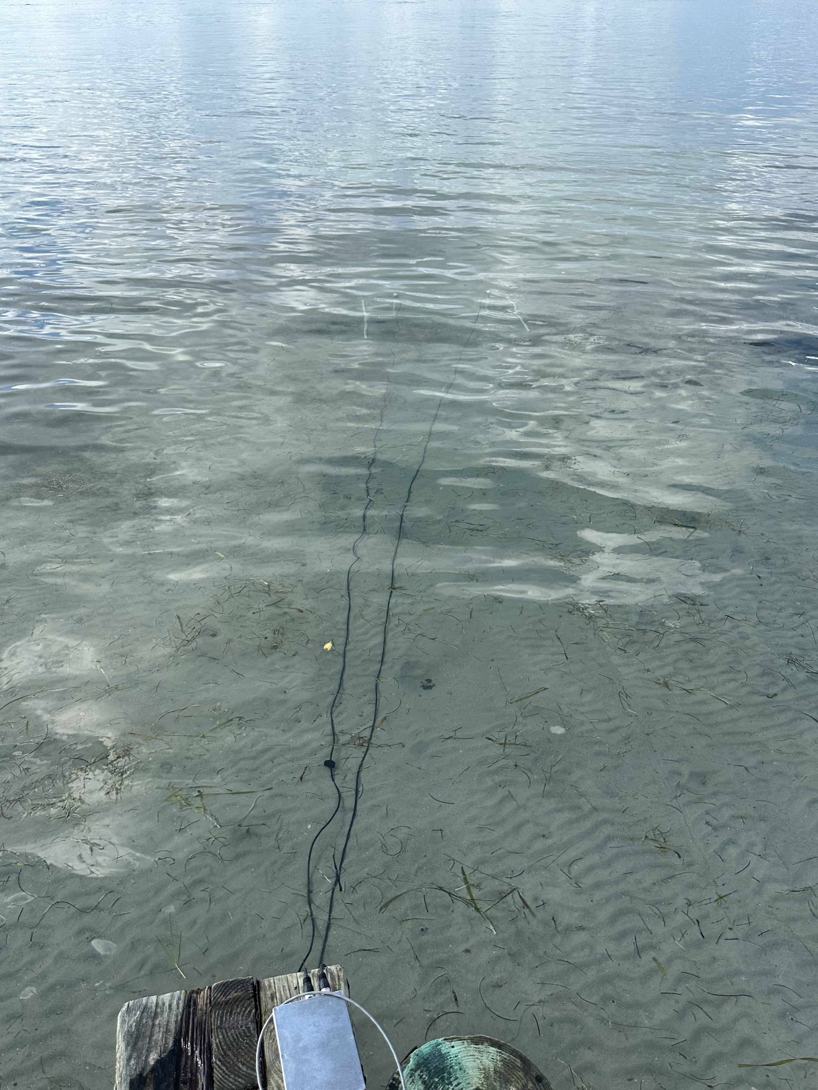
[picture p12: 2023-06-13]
experiments/20230611/submerged hydrophones.jpg

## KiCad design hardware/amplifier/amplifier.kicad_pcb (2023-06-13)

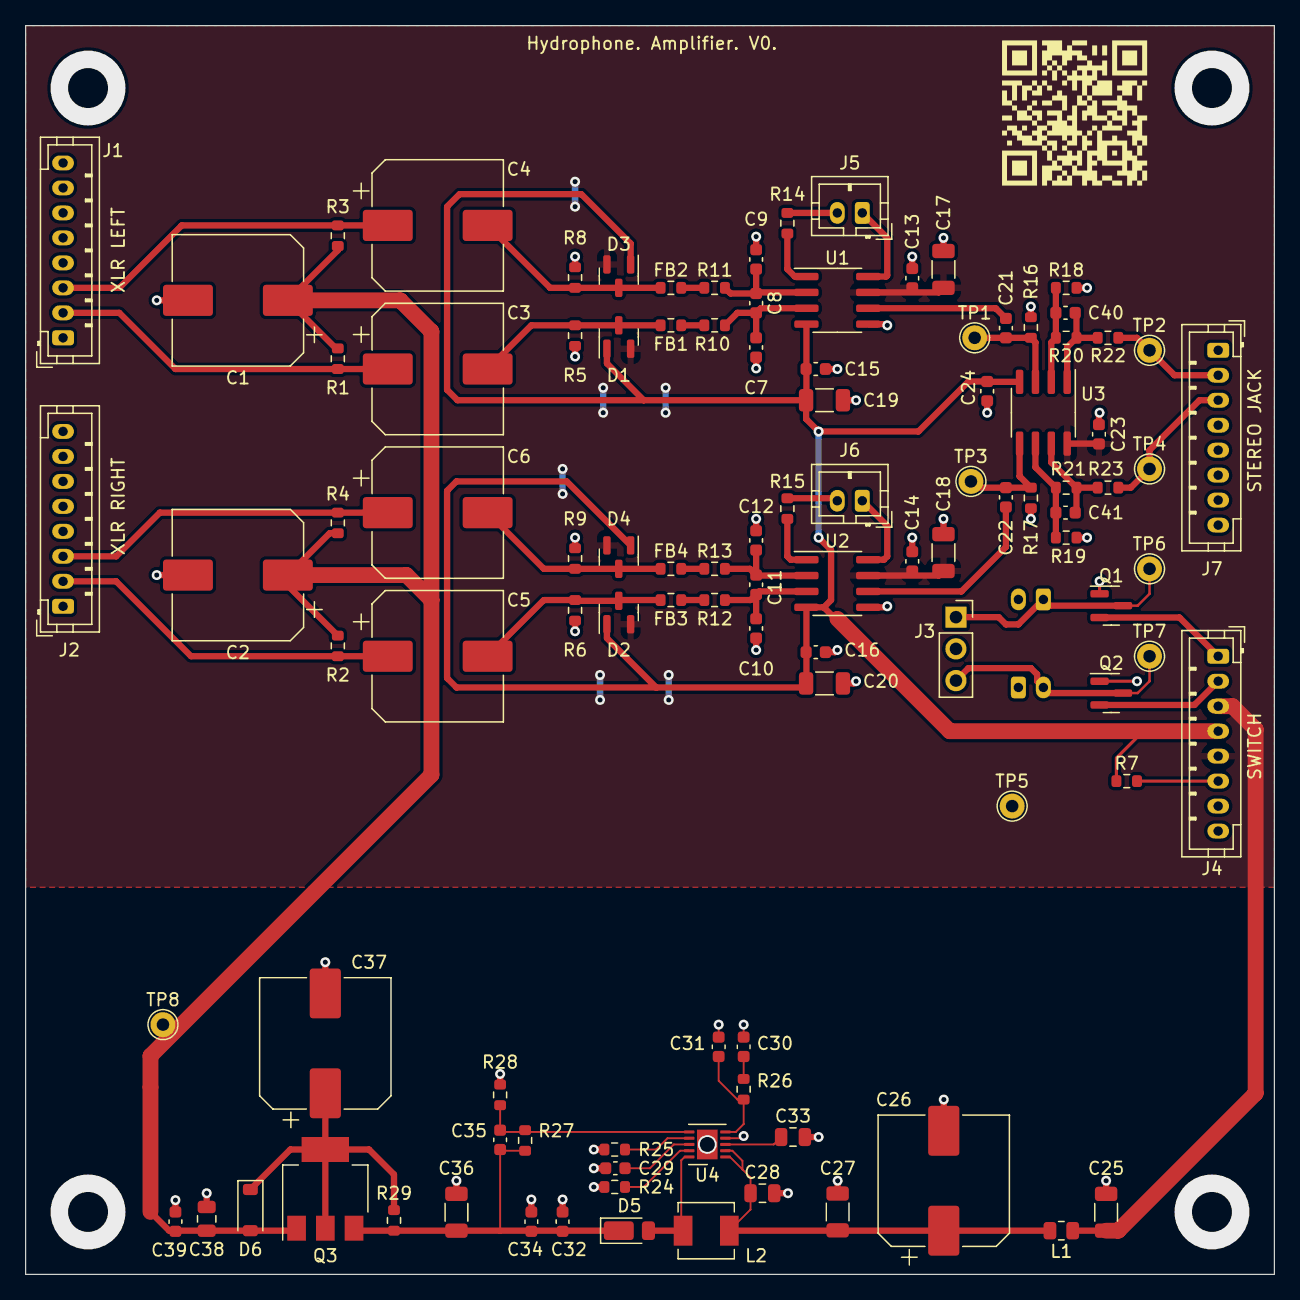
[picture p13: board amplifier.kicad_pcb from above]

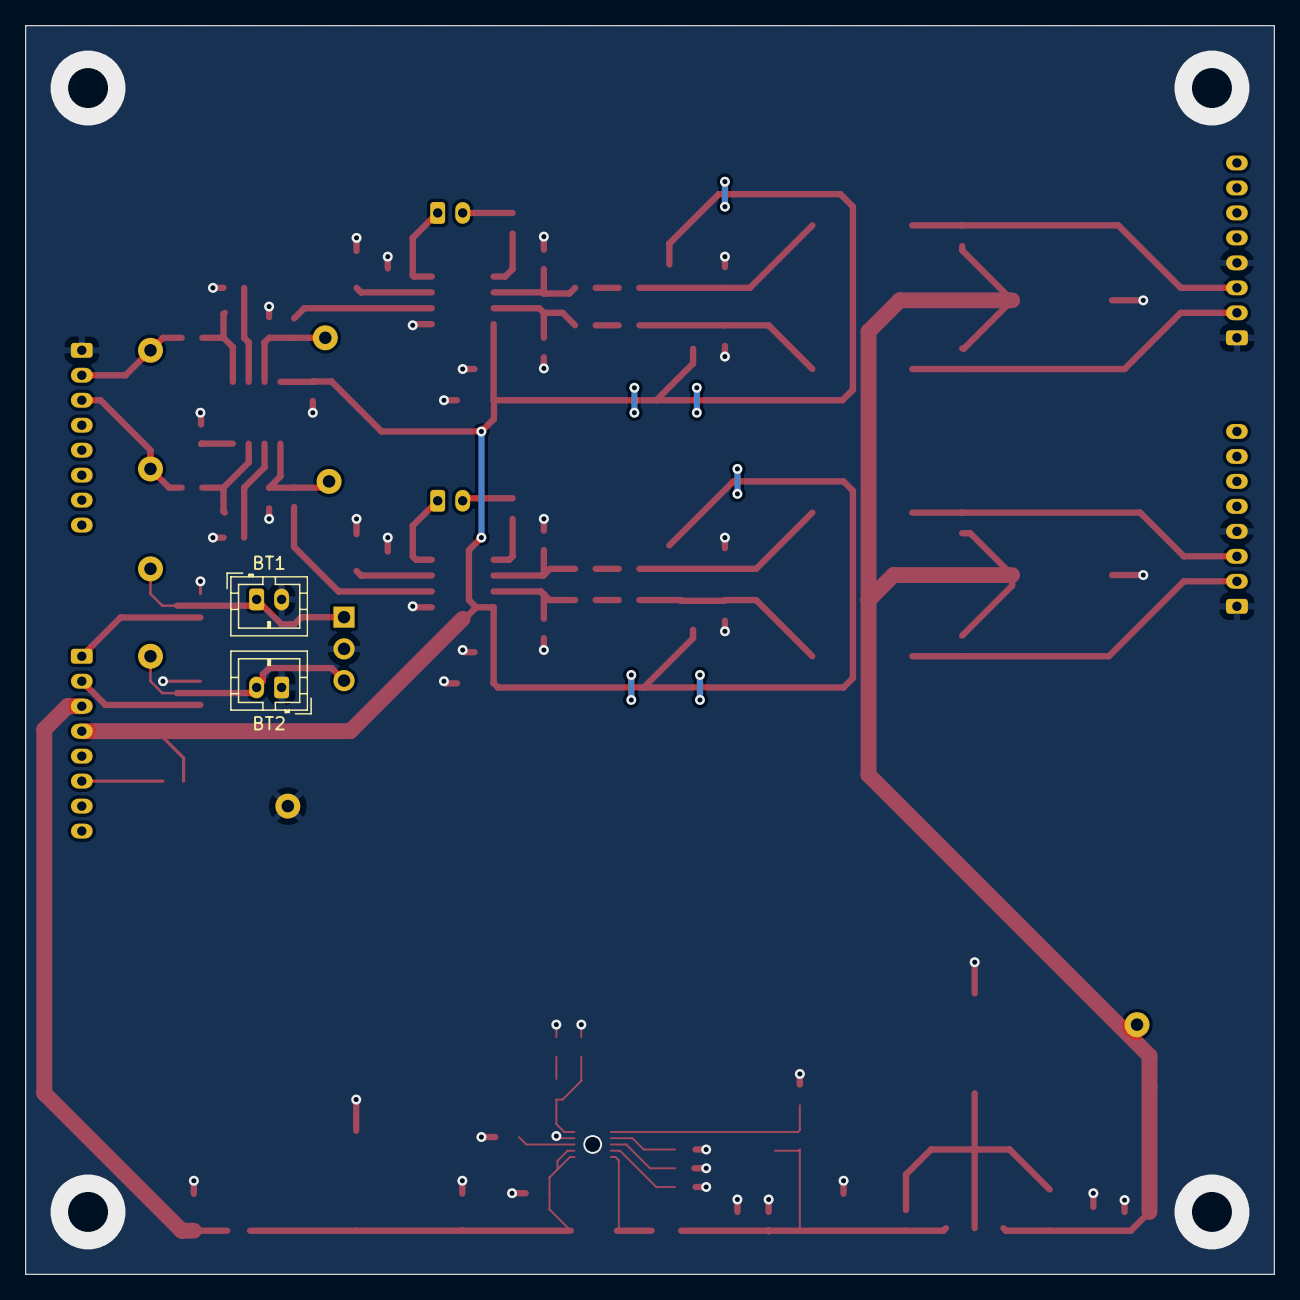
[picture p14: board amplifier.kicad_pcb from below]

Board: 2 copper layers, 100.0 x 100.0 mm, 106 parts (2 on the bottom side), 52 nets.

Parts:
BT1, BT2: 9V; JST_PH_B2B-PH-K_1x02_P2.00mm_Vertical
C1, C2, C3, C4, C5, C6, C26: 47u; CP_Elec_10x10
C7, C9, C10, C12, C30: 1n; C_0603_1608Metric
C8, C11, C39: 10n; C_0603_1608Metric
C13, C14, C15, C16, C23, C24, C32, C34: 0.1u; C_0603_1608Metric
C17, C18, C19, C20, C27, C36: 10u; C_1206_3216Metric
C21, C22, C40, C41: DNP; C_0603_1608Metric
C25: 4.7u; C_1206_3216Metric
C28, C33, C38: 1u; C_0805_2012Metric
C29: 0.22u; C_0603_1608Metric
C31: 10p; C_0603_1608Metric
C35: 4.7p; C_0603_1608Metric
C37: 100u; CP_Elec_10x10
D1, D2, D3, D4: BAV199; SOT-23
D5: DFLS260-7; D_PowerDI-123
D6: 1N4148; D_SOD-123
FB1, FB2, FB3, FB4: FerriteBead; R_0603_1608Metric
J1, J2, J4, J7: Conn_01x04; JST_PH_B8B-PH-K_1x08_P2.00mm_Vertical
J3: Conn_01x03; PinSocket_1x03_P2.54mm_Vertical
J5, J6: Conn_01x02; JST_PH_B2B-PH-K_1x02_P2.00mm_Vertical
L1: 0.47u; R_0805_2012Metric
L2: 6.8u; L_Wuerth_74437324068
Q1, Q2: SSM3J338R,LF; SOT-23
Q3: SBCP56-16T1G; SOT-223-3_TabPin2
R1, R2, R3, R4: 6.8k; R_0603_1608Metric
R5, R6, R7, R8, R9: 2.2k; R_0603_1608Metric
R10, R11, R12, R13: 33; R_0603_1608Metric
R14, R15, R20, R21, R22, R23: 0; R_0603_1608Metric
R16, R17, R18, R19: DNP; R_0603_1608Metric
R24: 100k; R_0603_1608Metric
R25, R26: 22k; R_0603_1608Metric
R27: 1M; R_0603_1608Metric
R28: 34.8k; R_0603_1608Metric
R29: 499; R_0603_1608Metric
TP1, TP2, TP3, TP4, TP5, TP6, TP7, TP8: TestPoint; TestPoint_THTPad_D2.0mm_Drill1.0mm
U1, U2: AD8421; SOIC-8_3.9x4.9mm_P1.27mm
U3: OPA1688; SOIC-8_3.9x4.9mm_P1.27mm
U4: LT8362; DFN-10-1EP_3x3mm_P0.5mm_EP1.65x2.38mm

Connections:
+9V: C13.1, C14.1, C17.1, C18.1, C23.1, C25.1, D1.2 (A), D2.2 (A), D3.2 (A), D4.2 (A), J4.3, J4.5, L1.1, U1.7 (V+), U2.7 (V+), U3.8 (V+)
+48V: C1.1, C2.1, C38.1, C39.1, D6.2 (A), Q3.1 (E), R1.2, R2.2, R3.2, R4.2, TP8.1
-9V: C15.1, C16.1, C19.1, C20.1, C24.1, D1.1 (K), D2.1 (K), D3.1 (K), D4.1 (K), J4.4, R7.1, U1.4 (V-), U2.4 (V-), U3.4 (V-)
/HP_Left: J7.2, R22.1, TP2.1
/HP_Right: J7.3, R23.1, TP4.1
/vbat+: BT1.1 (+), J3.1, Q1.3 (D), TP6.1
/vbat-: BT2.2 (-), J3.3, Q2.3 (D), TP7.1
GND: BT1.2 (-), BT2.1 (+), C1.2, C2.2, C7.1, C9.2, C10.1, C12.2, C13.2, C14.2, C15.2, C16.2, C17.2, C18.2, C19.2, C20.2, C23.2, C24.2, C25.2, C26.2, C27.2, C28.2, C29.2, C30.2, C31.2, C32.2, C33.2, C34.2, C36.2, C37.2, C38.2, C39.2, J1.1, J1.4, J2.1, J2.4, J3.2, J7.1, Q1.1 (G), Q2.1 (G), R5.1, R6.1, R8.1, R9.1, R16.2, R17.2, R18.2, R19.2, R24.1, R25.1, R28.1, TP5.1, U1.5 (Ref), U2.5 (Ref), U4.4 (BIAS), U4.11 (GND)
unnamed: C3.2, D1.3 (K), FB1.1, R5.2
unnamed: C4.2, D3.3 (K), FB2.1, R8.2
unnamed: C5.2, D2.3 (K), FB3.1, R6.2
unnamed: C6.2, D4.3 (K), FB4.1, R9.2
unnamed: C21.1, U1.6
unnamed: C22.1, U2.6
unnamed: C30.1, R26.1
unnamed: C40.2, R20.1, R22.2, U3.1
unnamed: C41.2, R21.1, R23.2, U3.7
unnamed: D5.2 (A), L2.2, U4.10 (SW)
unnamed: C32.1, C34.1, C35.1, C36.1, D5.1 (K), Q3.3 (C), R27.2, R29.2
unnamed: C37.1, D6.1 (K), Q3.2 (B), R29.1
unnamed: FB1.2, R10.1
unnamed: FB2.2, R11.1
unnamed: FB3.2, R12.1
unnamed: FB4.2, R13.1
unnamed: C3.1, J1.2, R1.1
unnamed: C4.1, J1.3, R3.1
unnamed: C5.1, J2.2, R2.1
unnamed: C6.1, J2.3, R4.1
unnamed: J4.1, Q1.2 (S)
unnamed: J4.2, Q2.2 (S)
unnamed: J4.6, R7.2
unnamed: J5.1, U1.8 (Rg)
unnamed: J5.2, R14.1
unnamed: J6.1, U2.8 (Rg)
unnamed: J6.2, R15.1
unnamed: R14.2, U1.1 (Rg)
unnamed: R15.2, U2.1 (Rg)
unnamed: C7.2, C8.1, R10.2, U1.3 (+)
unnamed: C8.2, C9.1, R11.2, U1.2 (-)
unnamed: C10.2, C11.1, R12.2, U2.3 (+)
unnamed: C11.2, C12.1, R13.2, U2.2 (-)
unnamed: C21.2, R16.1, TP1.1, U3.3 (+)
unnamed: C40.1, R18.1, R20.2, U3.2 (-)
unnamed: C22.2, R17.1, TP3.1, U3.5 (+)
unnamed: C41.1, R19.1, R21.2, U3.6 (-)
unnamed: C26.1, C27.1, C28.1, L1.2, L2.1, U4.1 (EN/UVLO), U4.2 (Vin)
unnamed: C35.2, R27.1, R28.2, U4.6 (FBX)
unnamed: C33.1, U4.3 (INTVcc)
unnamed: R25.2, U4.7 (RT)
unnamed: C29.1, U4.8 (SS)
unnamed: R24.2, U4.9 (SYNC/MODE)
unnamed: C31.1, R26.2, U4.5 (VC)
